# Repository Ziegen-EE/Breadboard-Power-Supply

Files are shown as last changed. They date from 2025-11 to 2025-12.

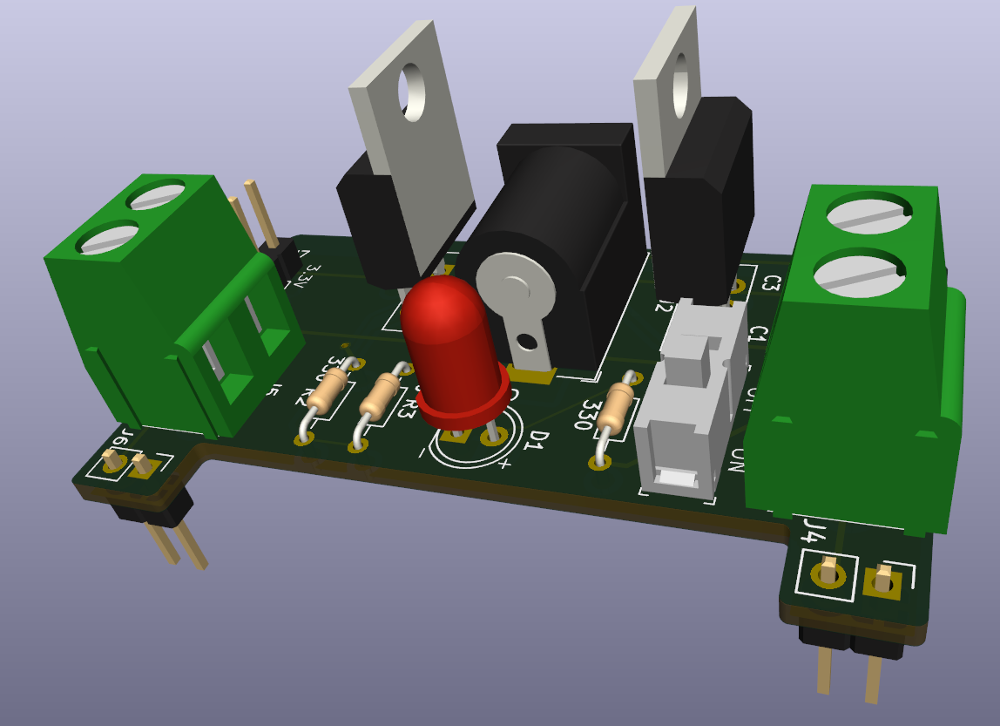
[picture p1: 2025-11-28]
Breadboard Power Supply/KiCad/PCB/3D_PCB.png

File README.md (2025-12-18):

# Breadboard Power Supply

A compact PCB breadboard power supply designed to provide clean, stable **3.3V and 5V** rails for prototyping. It features onboard regulation, switchable voltage outputs, and full compatibility with standard breadboards—making it ideal for hobbyists, students, and rapid development workflows.

---

## Features

- Selectable **3.3V / 5V** regulated outputs  
- Standard breadboard-friendly dual-rail layout  
- Barrel jack + toggle power switch  
- High-quality capacitors for stable operation  
- Compact through-hole design, easy to assemble  

---

## Bill of Materials (BOM)

| | Reference Designator | DNP | Part Name | Manufacturer | MPN | Qty | Footprint | Link | Notes | Price | Total Price |
|---:|---|-----|---|---|---|----:|---|---|---|---:|---:|
| 1 | J1 | No | Barrel Jack Switch | MPD (Memory Protection Devices) | EJ508B | 1 | THT | Link | 12V | 1.22 | 99.29 |
| 2 | S1 | No | Switch | E-Switch | EG1218 | 1 | THT | Link | — | 0.84 | — |
| 3 | C1 | No | Capacitor | TDK Corporation | FK20X7S1H106KR000 | 1 | THT | Link | 10uF | 1.04 | — |
| 4 | C2 | No | Capacitor | Murata Electronics | RCER72A105K2DBH03A | 1 | THT | Link | 1uF | 0.79 | — |
| 5 | C3 | No | Capacitor | KEMET | C320C104K5R5TA | 1 | THT | Link | 0.1uF | 0.30 | — |

You can view the **full BOM** spreadsheet using the link below:  

[Full BOM (Google Sheets)](https://docs.google.com/spreadsheets/d/1jAm3g67_ThedoSjCjsSPfpU4eJjXTLUuRc0bo3Tdfd8/edit?usp=sharing)

---

## Assembly

1. Solder all passive components first (capacitors, resistors if any).  
2. Install connectors and switches.  
3. Add voltage regulators and verify orientation.  
4. Test each rail individually before inserting into a breadboard.  

---

## Usage

1. Plug the module into your breadboard rails.  
2. Connect power via the barrel jack.  
3. Use the onboard switch to turn the supply on/off.

---

## License

This project is released under the **MIT License**. Feel free to use, modify, and share.

## Some Pics of the Design!

Schematic

2D_PCB

3D_PCB

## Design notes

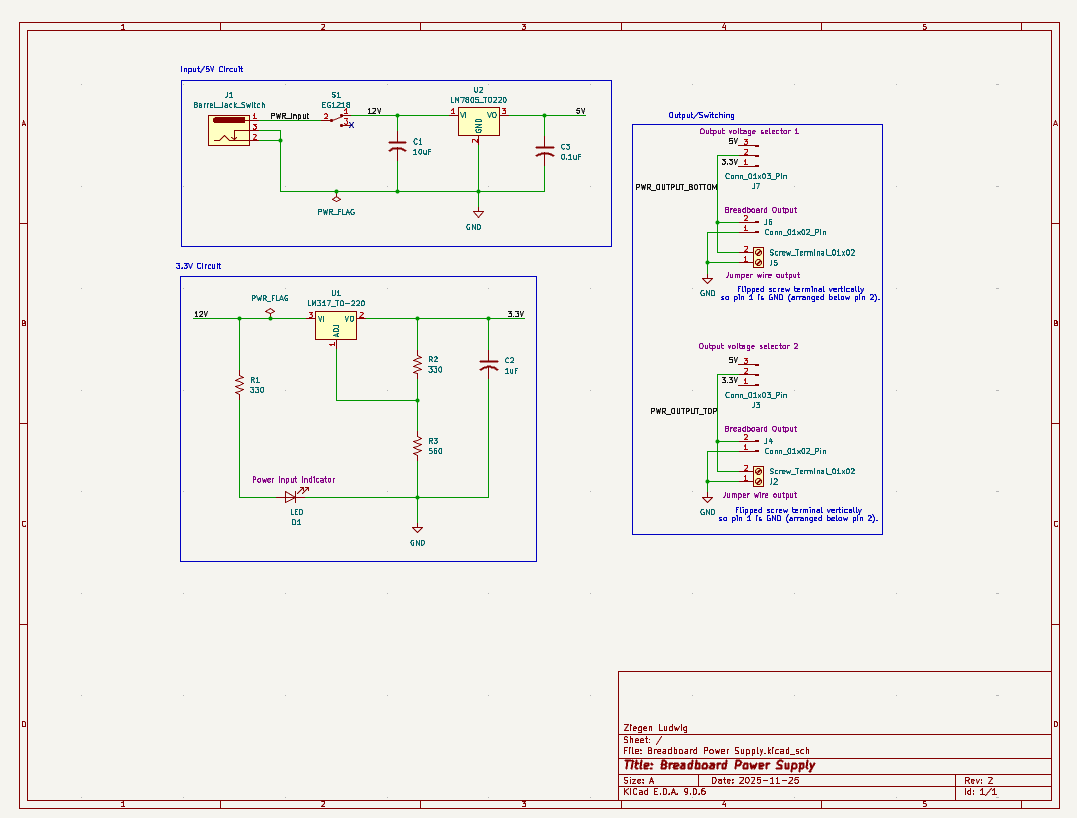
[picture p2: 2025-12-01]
Breadboard Power Supply/KiCad/Schematic/Schematic.png

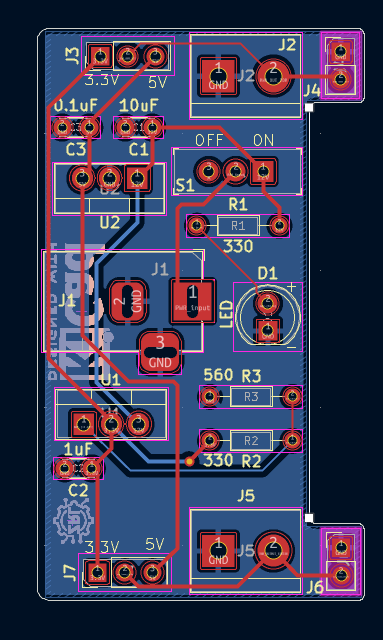
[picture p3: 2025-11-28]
Breadboard Power Supply/KiCad/PCB/2D_PCB.png

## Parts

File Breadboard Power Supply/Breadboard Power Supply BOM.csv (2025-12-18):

 | Reference Designator | DNP | Part Name | Manufacturer | MPN | Qty | Footprint | Link | Notes | Price | Total Price
1 | J1 | No | Barrel Jack Switch | MPD (Memory Protection Devices) | EJ508B | 1 | THT | Link | 12V | 1.22 | 35.92
2 | S1 | No | Switch | E-Switch | EG1218 | 1 | THT | Link |  | 0.84
3 | C1 | No | Capacitor | TDK Corporation | FK20X7S1H106KR000 | 1 | THT | Link | 10uF | 1.04
4 | C2 | No | Capacitor | Murata Electronics | RCER72A105K2DBH03A | 1 | THT | Link | 1uF | 0.79
5 | C3 | No | Capacitor | KEMET | C320C104K5R5TA | 1 | THT | Link | 0.1uF | 0.3
6 | U1 | No | Power Regulator | STMicroelectronics | LM317T | 1 | THT | Link |  | 0.56
7 | U2 | No | Power Regulator | Texas Instruments | LM7805CT/NOPB | 1 | THT | Link |  | 1.8
8 | R1, R2 | No | Resistor | TE Connectivity Passive Product | ROX1SJ330R | 2 | THT | Link | 330 | 0.1
9 | R3 | No | Resistor | TE Connectivity Passive Product | ROX1SJ560R | 1 | THT | Link | 560 | 0.1
10 | D1 | No | LED | Lumex Opto/Components Inc. | SSL-LX3054ID | 1 | THT | Link | Red | 0.36
11 | J7, J3 | No | 1x3 Pin Header Male | Samtec Inc. | TSW-101-24-G-T | 2 | THT | Link |  | 0.39
12 | J6, J4 | No | 1x2 Pin Header Male | Amphenol ICC (FCI) | 67997-402HLF | 2 | THT | Link |  | 0.15
13 | J5, J2 | No | 1x2 Screw Terminal | Phoenix Contact | 1729128 | 2 | THT | Link |  | 1.33
14 | N/a | N/a | PCB | JLB PCB | N/a | 5 | N/a |  |  | 17.08
15 | N/a | N/a | Power Brick | inShareplus | N/a | 1 | N/a | Link |  | 7.89

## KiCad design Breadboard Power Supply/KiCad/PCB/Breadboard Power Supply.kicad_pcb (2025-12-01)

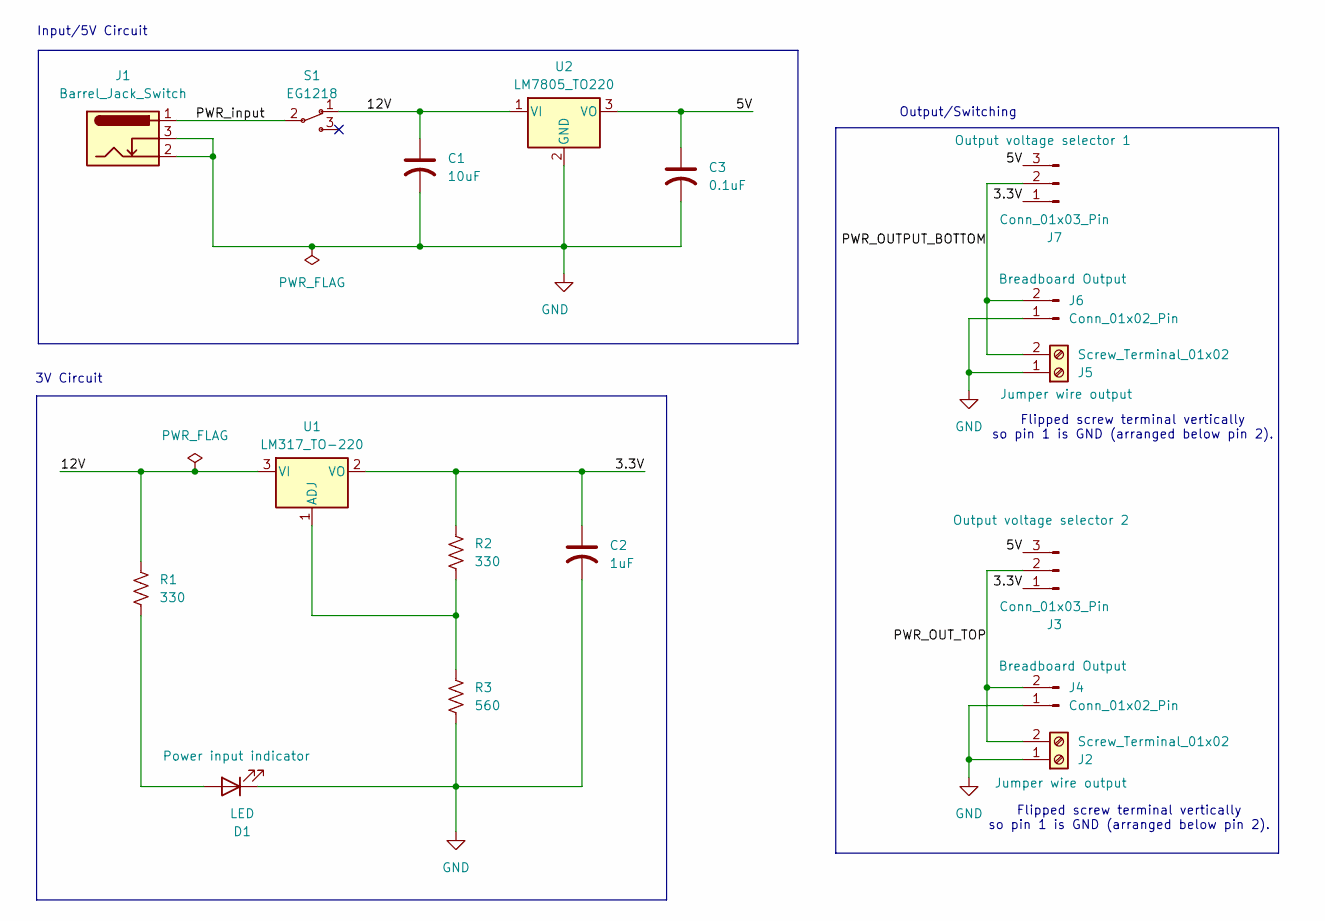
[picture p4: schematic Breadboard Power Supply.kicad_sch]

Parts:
C1: 10uF; C_Disc_D3.0mm_W1.6mm_P2.50mm; MPN FK20X7S1H106KR000
C2: 1uF; C_Disc_D3.0mm_W1.6mm_P2.50mm; MPN RCER72A105K2DBH03A
C3: 0.1uF; C_Disc_D3.0mm_W1.6mm_P2.50mm; MPN S104Z93Z5VL83L0R
D1: LED; LED_D5.0mm; MPN SSL-LX3054ID
J1: Barrel_Jack_Switch; BarrelJack_Horizontal; MPN EJ508B
J2, J5: Screw_Terminal_01x02; TerminalBlock_bornier-2_P5.08mm; MPN 1729128
J3, J7: Conn_01x03_Pin; PinHeader_1x03_P2.54mm_Vertical; MPN TSW-101-24-G-T
J4, J6: Conn_01x02_Pin; PinHeader_1x02_P2.54mm_Vertical; MPN 67997-402HLF
R1, R2: 330; R_Axial_DIN0204_L3.6mm_D1.6mm_P7.62mm_Horizontal; MPN ROX1SJ330R
R3: 560; R_Axial_DIN0204_L3.6mm_D1.6mm_P7.62mm_Horizontal; MPN ROX1SJ560R
S1: EG1218; Switch_Slide_11.6x4mm_EG1218; MPN EG1218
U1: LM317_TO-220; TO-220-3_Vertical; MPN LM317T
U2: LM7805_TO220; TO-220-3_Vertical; MPN LM7805CT/NOPB

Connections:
/3.3V: C2.1, J3.1, J7.1, R2.2, U1.2 (VO)
/5V: C3.1, J3.3, J7.3, U2.3 (VO)
/12V: C1.1, R1.2, S1.1, U1.3 (VI), U2.1 (VI)
/PWR_OUTPUT_BOTTOM: J5.2, J6.2, J7.2
/PWR_OUTPUT_TOP: J2.2, J3.2, J4.2
/PWR_input: J1.1, S1.2
GND: C1.2, C2.2, C3.2, D1.1 (K), J1.2, J1.3, J2.1, J4.1, J5.1, J6.1, R3.1, U2.2 (GND)
unnamed: D1.2 (A), R1.1
unnamed: R2.1, R3.2, U1.1 (ADJ)

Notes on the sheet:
Output/Switching
Input/5V Circuit
Flipped screw terminal vertically so pin 1 is GND (arranged below pin 2).
3V Circuit

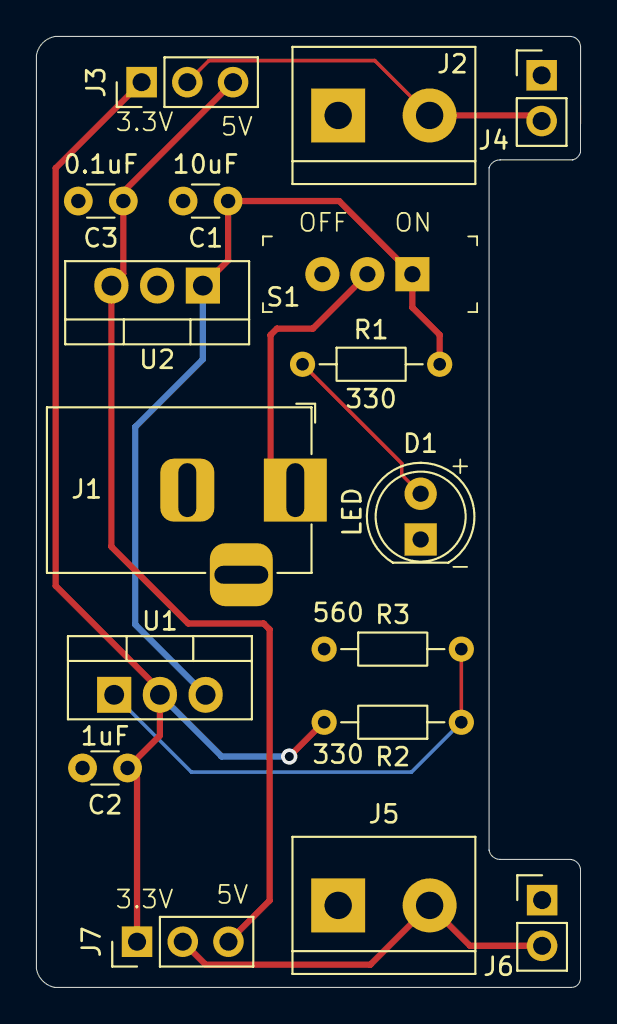
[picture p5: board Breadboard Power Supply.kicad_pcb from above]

Board: 2 copper layers, 30.2 x 52.8 mm, 17 parts (0 on the bottom side), 9 nets.

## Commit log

2025-11-28 Revise README for improved clarity and structure
    Updated the README to enhance clarity and added detailed sections including features, BOM, assembly instructions, and usage.
2025-12-18 Update C3 capacitor details in README
